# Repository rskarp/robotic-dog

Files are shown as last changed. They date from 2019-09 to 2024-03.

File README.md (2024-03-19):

# Robotic Dog
This project was conducted as my Honors project in Computer Science at Colby College from January-May 2019. The project included simulating robotic limb movement using Python, programming and Arduino Uno to control 12 servo motors (3 per limb) using C++, designing robotic dog limbs using CAD software, laser cutting the limbs and assembling the dog with servo motors, writing a paper on this work, and giving an oral presentation.
RoboticDog

## Project Description
As robots develop the capability to perform more complicated tasks, stable locomotion will become a basic required element of all mobile robots. While walking robots may have various numbers of legs, four legs provide a reasonably stable platform without requiring excessive amounts of power and resources that would be necessary to control robots with more limbs. It is useful to base the gait patterns of these robotic quadrupeds on existing quadrupeds in nature, such as dogs. This project explores three different joint control algorithms in simulation using Python3.7 and on a robotic dog controlled by an Arduino Uno. The three algorithms include an inverse kinematics solution based on a predetermined foot trajectory, a forward kinematic solution based on joint angles collected from biological data, and a waypoint solution, which was found to be optimal for this project. The robot described in this paper was created specifically as a tool to explore different motor control strategies for reproducing canine gait patterns in robotic limbs; however, these motor control concepts are applicable to more complicated limbed robots as well.

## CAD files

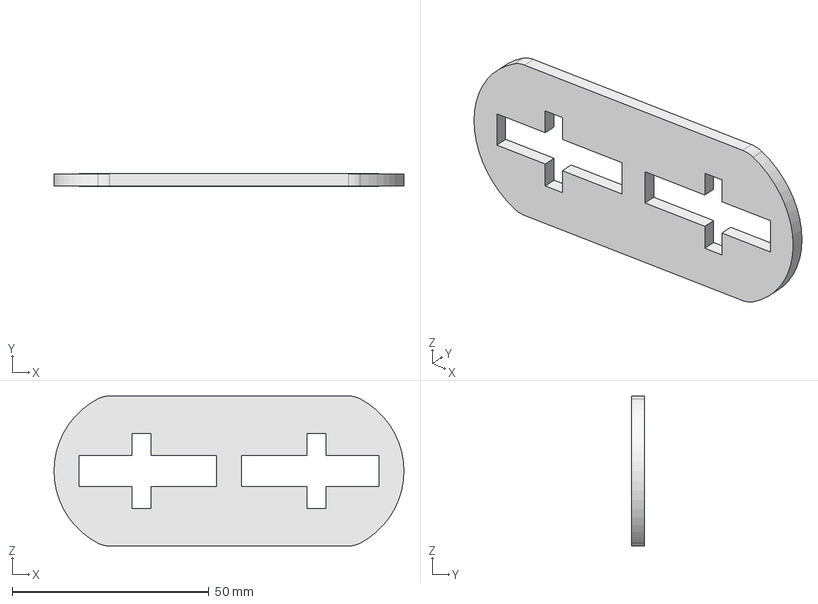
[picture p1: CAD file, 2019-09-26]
CAD/thigh2.FCStd
88.9 x 3.18 x 38.1 mm

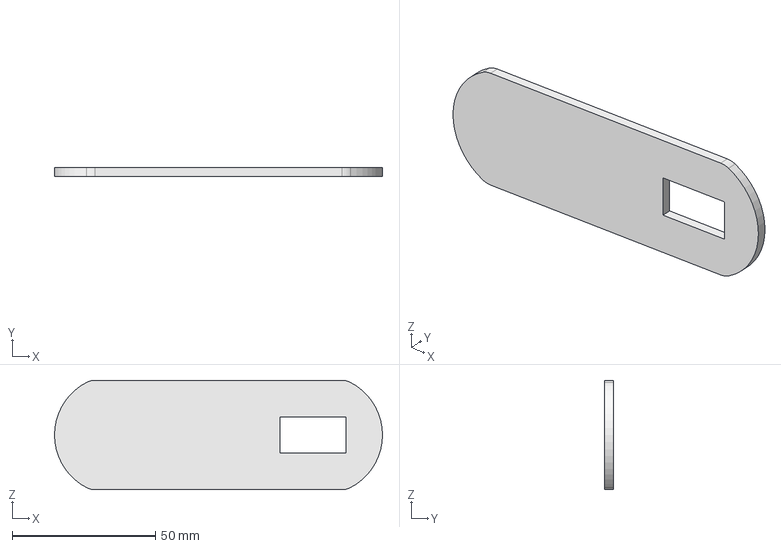
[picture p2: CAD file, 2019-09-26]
CAD/shin3.FCStd
114.3 x 3.17 x 38.1 mm

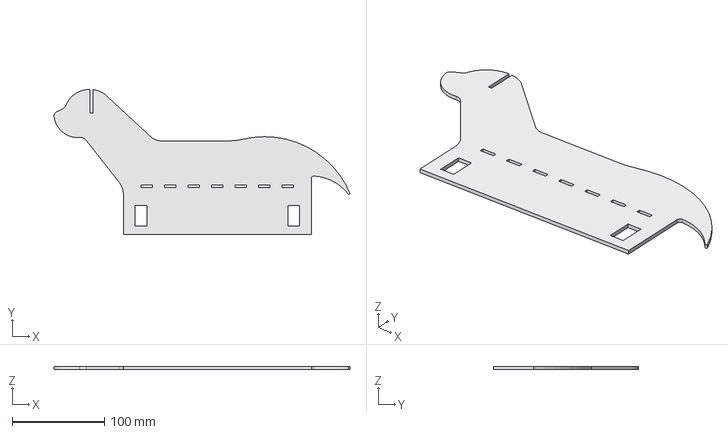
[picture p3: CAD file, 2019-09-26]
CAD/bodySideSlit.FCStd
320.2 x 157.2 x 3.17 mm

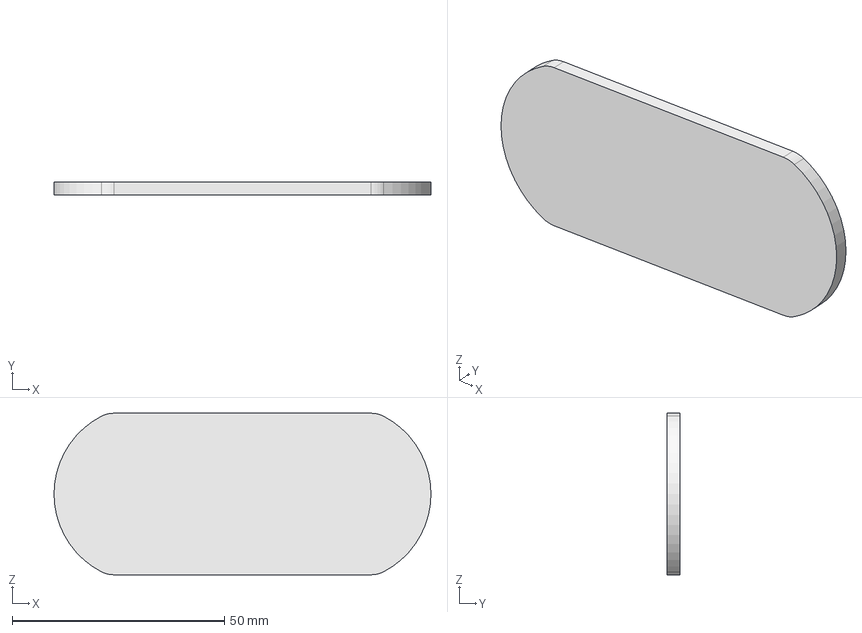
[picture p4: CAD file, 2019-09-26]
CAD/thigh3.FCStd
88.9 x 3.18 x 38.1 mm

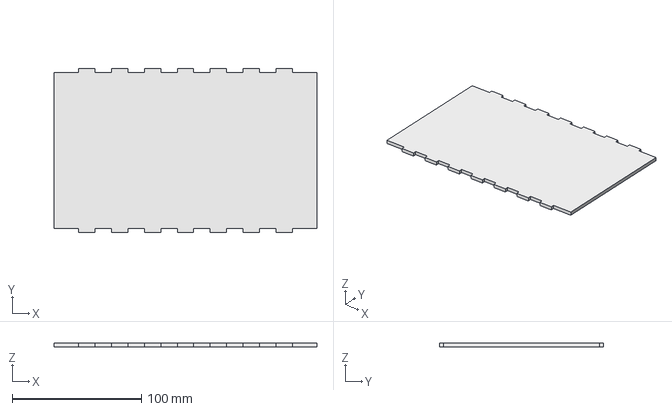
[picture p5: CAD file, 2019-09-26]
CAD/bodyBase.FCStd
203.2 x 127.0 x 3.17 mm

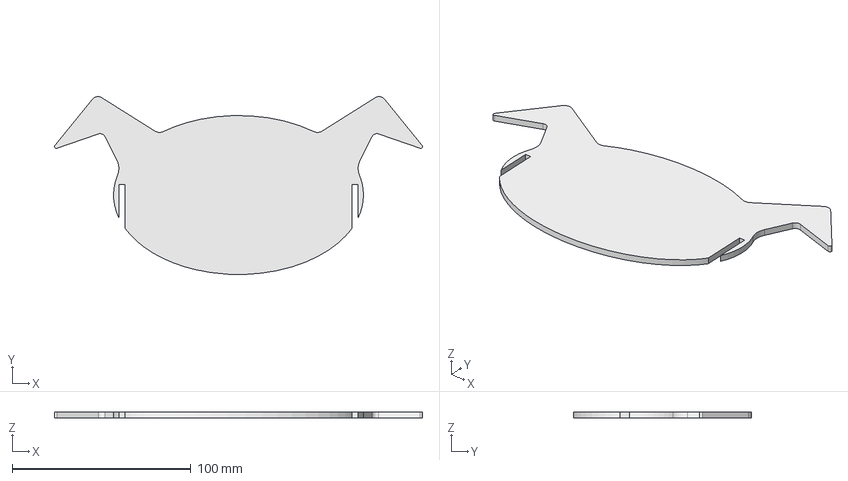
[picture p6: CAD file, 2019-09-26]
CAD/head.FCStd
205.7 x 99.4 x 3.17 mm

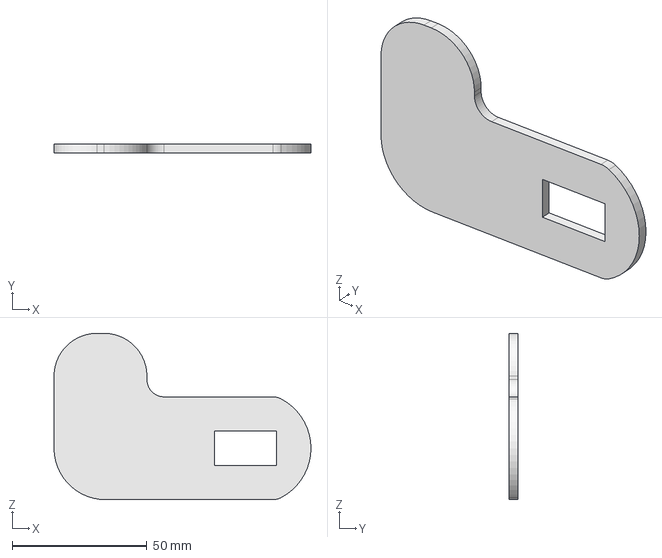
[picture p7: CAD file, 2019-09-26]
CAD/foot2.FCStd
95.2 x 3.17 x 61.6 mm

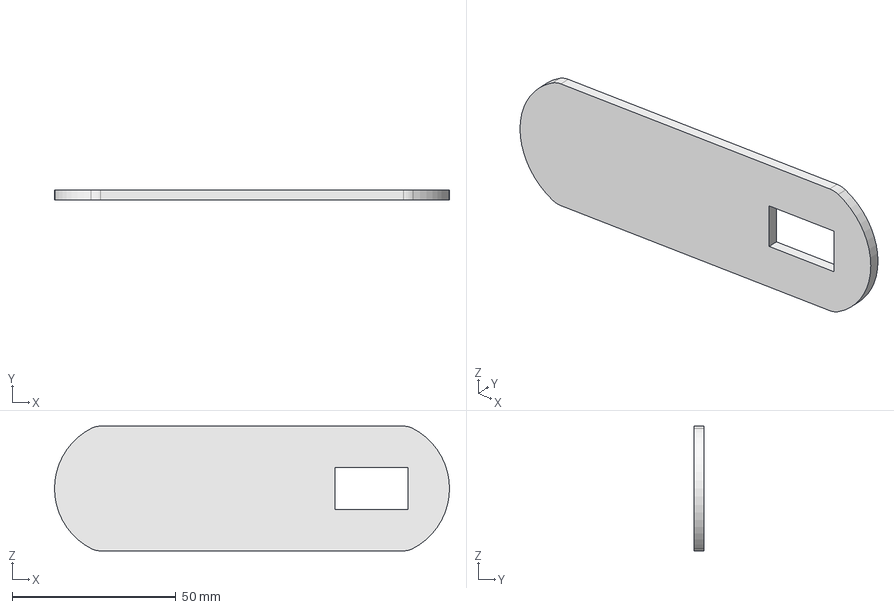
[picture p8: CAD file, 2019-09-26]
CAD/foot.FCStd
120.7 x 3.18 x 38.1 mm

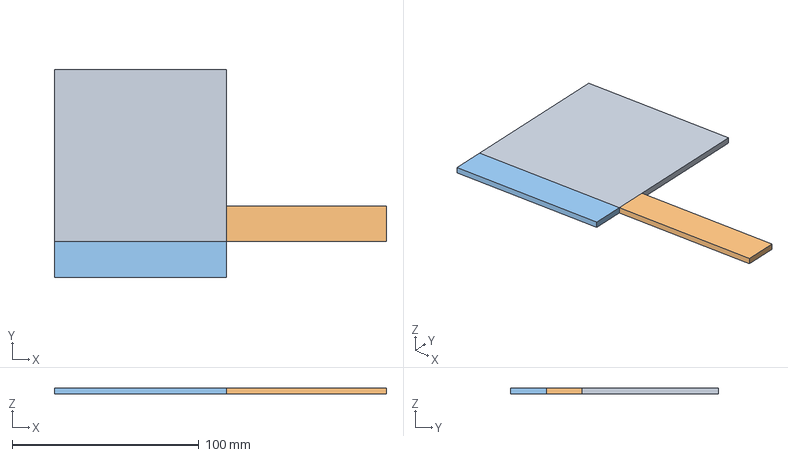
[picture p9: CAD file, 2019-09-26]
CAD/basePlate.FCStd
177.8 x 111.1 x 3.17 mm
Base
Back
Side

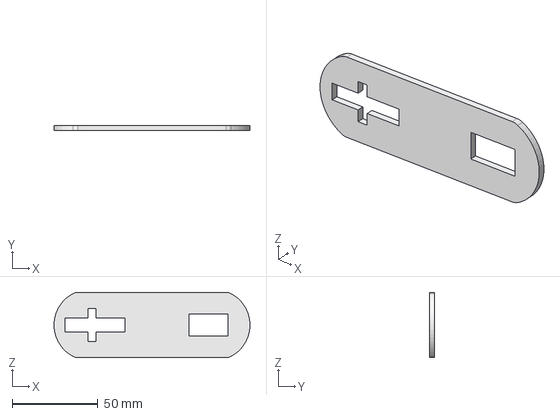
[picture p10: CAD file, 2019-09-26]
CAD/shin2.FCStd
114.3 x 3.17 x 38.1 mm

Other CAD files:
CAD/shin1.FCStd
CAD/thigh1.FCStd

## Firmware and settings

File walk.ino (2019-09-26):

/*
 * Riley Karp
 * CS483 Honors Research - Robotic Dog
 * Leg Control - Step to target location
 * 10 March 2019
 */

 #include <avr/io.h>
 #include "Adafruit_PWMServoDriver.h" // PWM Motor Driver
 #include "USART.h" //library w/ serial bus functions
 #include <stdio.h> // library w/ sprintf() string formatting

 /* Define constants */
 #define servoMin  170 // min pulse length out of 4096 (0 degrees)
 #define servoMed  370 // med pulse length out of 4096 (90 degrees)
 #define servoMax  510 // max pulse length out of 4096 (130 degrees)
 #define hipHL 0 // motor number for FRONT LEFT HIP
 #define kneeHL 1 // motor number for FRONT LEFT KNEE
 #define ankleHL 2 // motor number for FRONT LEFT ANKLE
 #define hipHR 4 // motor number for HIND LEFT HIP
 #define kneeHR 5 // motor number for HIND LEFT KNEE
 #define ankleHR 6 // motor number for HIND LEFT ANKLE
 #define hipFL 8 // motor number for FRONT RIGHT HIP
 #define kneeFL 9 // motor number for FRONT RIGHT KNEE
 #define ankleFL 10 // motor number for FRONT RIGHT ANKLE
 #define hipFR 12 // motor number for HIND RIGHT HIP
 #define kneeFR 13 // motor number for HIND RIGHT KNEE
 #define ankleFR 14 // motor number for HIND RIGHT ANKLE
 #define pi 3.141592653589793238462643383279502884197169399375105820974944592307816406286208998

 /* Initialize global variables */
 const int numAngles = 8; // initialize number of waypoint angles
 Adafruit_PWMServoDriver driver = Adafruit_PWMServoDriver(); // motor driver object

// float hipAngles[numAngles] = {-107.53,-115.32, -120.90,-120.89,-122.7,-133.56,-132.03,-126.2,-117.23,-105,-79.74,-88.8,-104.19};
// float kneeAngles[numAngles] = {16.76,15.07,11.30,5.73,0.94,7.32,12.75,16.97,20,21.15,13.79,13.34,14.76};
// float ankleAngles[numAngles] = {31.44,35.70,34.52,23.72,15.29,44.96,53.55,55.09,51,41.14,12,16.81,31};
 
 float hipAngles[numAngles] = {-7.53,25,0,-33,-25,-10,10,15};
 float kneeAngles[numAngles] = {-36.76,-43,-45,-48,-30,-40,-35,-30};
 float ankleAngles[numAngles] = {31.44,48,60,66,45,40,30,38};
 int pulse;

 bool FL = false;
 bool FR = true;
 bool HL = false;
 bool HR = false;
 int FLi = 6;
 int FRi = 1;
 int HLi = 5;
 int HRi = 7;

 // FRONT LEFT FOOT
 float thetaH_FL = (hipAngles[0])*pi/180;
 float thetaK_FL = (kneeAngles[0])*pi/180;
 float thetaA_FL = (ankleAngles[0])*pi/180;
 float targetH_FL = (hipAngles[FLi])*pi/180;
 float targetK_FL = (kneeAngles[FLi])*pi/180;
 float targetA_FL = (ankleAngles[FLi]-5)*pi/180;

 // FRONT RIGHT FOOT
 float thetaH_FR = (hipAngles[0])*pi/180;
 float thetaK_FR = (kneeAngles[0])*pi/180;
 float thetaA_FR = (ankleAngles[0])*pi/180;
 float targetH_FR = (hipAngles[FRi])*pi/180;
 float targetK_FR = (kneeAngles[FRi])*pi/180;
 float targetA_FR = (ankleAngles[FRi])*pi/180;

 // HIND LEFT FOOT
 float thetaH_HL = (hipAngles[0])*pi/180;
 float thetaK_HL = (kneeAngles[0])*pi/180;
 float thetaA_HL = (ankleAngles[0])*pi/180;
 float targetH_HL = (hipAngles[HLi])*pi/180;
 float targetK_HL = (kneeAngles[HLi])*pi/180;
 float targetA_HL = (ankleAngles[HLi]+8)*pi/180;

 // HIND RIGHT FOOT
 float thetaH_HR = (hipAngles[0])*pi/180;
 float thetaK_HR = (kneeAngles[0])*pi/180;
 float thetaA_HR = (ankleAngles[0])*pi/180;
 float targetH_HR = (hipAngles[HRi])*pi/180;
 float targetK_HR = (kneeAngles[HRi])*pi/180;
 float targetA_HR = (ankleAngles[HRi])*pi/180;

 
 /* Returns the pulse length corresponding to the given angle between 0 and 130 degrees (input angle is in radians) */
 int radToPulse( int joint, float rad ) {
  // y = mx + b for DH angle to pulse
  pulse = int(float(servoMed-servoMin)*rad/(pi/2) + servoMed);
  // make sure pulse is within range
  if( pulse > servoMax ) {
    pulse = servoMax;
  }
  else if(pulse < servoMin) {
    pulse = servoMin;
  }
  return pulse;
 }

 /* Moves the given joint to the given angle */
 void moveJoint( int joint, float angle ) {
  driver.setPWM( joint, 0, radToPulse(joint,angle) );
 }
 
 int main() {
  initUSART();
  init(); // haven't yet figured out why this is necessary, but it is
  driver.begin(); // start motor driver object
  driver.setPWMFreq(60); // analog servos run at ~60 hz
  
  DDRC = 0b00110000; // configure OC1B pin PC[5:4] as output
  SREG |= 0b10000000; // enable global interrupts

  // move legs to starting position
  moveJoint( hipFR, thetaH_FR );
  moveJoint( kneeFR, thetaK_FR );
  moveJoint( ankleFR, thetaA_FR );

  moveJoint( hipHL, -thetaH_HL );
  moveJoint( kneeHL, -thetaK_HL);
  moveJoint( ankleHL, -thetaA_HL );
  
  moveJoint( hipFL, -thetaH_FL );
  moveJoint( kneeFL, -thetaK_FL );
  moveJoint( ankleFL, -thetaA_FL );
  
  moveJoint( hipHR, thetaH_HR );
  moveJoint( kneeHR, thetaK_HR );
  moveJoint( ankleHR, thetaA_HR );
      
  printString("start\n");
  _delay_ms(1000);
    
  while( true) {
    // FRONT RIGHT LEG
    thetaH_FR += (targetH_FR-thetaH_FR)/20.0;
    thetaK_FR += (targetK_FR-thetaK_FR)/20.0;
    thetaA_FR += (targetA_FR-thetaA_FR)/20.0;
    moveJoint( hipFR, thetaH_FR );
    moveJoint( kneeFR, thetaK_FR );
    moveJoint( ankleFR, thetaA_FR );

    // HIND LEFT LEG
    thetaH_HL += (targetH_HL-thetaH_HL)/20.0;
    thetaK_HL += (targetK_HL-thetaK_HL)/20.0;
    thetaA_HL += (targetA_HL-thetaA_HL)/20.0;
    moveJoint( hipHL, -thetaH_HL );
    moveJoint( kneeHL, -thetaK_HL);
    moveJoint( ankleHL, -thetaA_HL );

    // FRONT LEFT LEG
    thetaH_FL += (targetH_FL-thetaH_FL)/20.0;
    thetaK_FL += (targetK_FL-thetaK_FL)/20.0;
    thetaA_FL += (targetA_FL-thetaA_FL)/20.0;
    moveJoint( hipFL, -thetaH_FL );
    moveJoint( kneeFL, -thetaK_FL );
    moveJoint( ankleFL, -thetaA_FL );

    // HIND RIGHT LEG
    thetaH_HR += (targetH_HR-thetaH_HR)/20.0;
    thetaK_HR += (targetK_HR-thetaK_HR)/20.0;
    thetaA_HR += (targetA_HR-thetaA_HR)/20.0;
    moveJoint( hipHR, thetaH_HR );
    moveJoint( kneeHR, thetaK_HR );
    moveJoint( ankleHR, thetaA_HR );

    if( (abs(thetaH_FR-targetH_FR) < 0.08) and
        (abs(thetaH_HL-targetH_HL) < 0.08) and
        (abs(thetaH_FL-targetH_FL) < 0.08) and
        (abs(thetaH_HR-targetH_HR) < 0.08) ) {

      // FRONT RIGHT UP
      if( FR ) {
        FRi += 1;
        if(FRi >= 4) {
          FR = false;
          HL = true;
          HLi = 0;
          FLi += 1;
          HRi -= 1;
        }
      }
      // HIND LEFT UP
      else if( HL ) {
        HLi += 1;
        if(HLi >= 4) {
          HL = false;
          HLi = 7;
          FL = true;
          FLi = 0;
          FRi += 1;
          HRi -= 1;
        }
      }
      // FRONT LEFT UP
      else if( FL ) {
        FLi += 1;
        if(FLi >= 4) {
          FL = false;
          HR = true;
          HRi = 0;
          FRi += 1;
          HLi -= 1;
        }
      }
      // HIND RIGHT UP
      else if(HR) {
        HRi += 1;
        if(HRi >= 4) {
          HR = false;
          HRi = 7;
          FR = true;
          FRi = 0;
          FLi += 1;
          HLi -= 1;
        }
      }

      // FRONT LEFT FOOT
      targetH_FL = (hipAngles[FLi])*pi/180;
      targetK_FL = (kneeAngles[FLi])*pi/180;
      targetA_FL = (ankleAngles[FLi]-5)*pi/180;
    
      // FRONT RIGHT FOOT
      targetH_FR = (hipAngles[FRi])*pi/180;
      targetK_FR = (kneeAngles[FRi])*pi/180;
      targetA_FR = (ankleAngles[FRi])*pi/180;
    
      // HIND LEFT FOOT
      targetH_HL = (hipAngles[HLi])*pi/180;
      targetK_HL = (kneeAngles[HLi])*pi/180;
      targetA_HL = (ankleAngles[HLi]+8)*pi/180;
    
      // HIND RIGHT FOOT
      targetH_HR = (hipAngles[HRi])*pi/180;
      targetK_HR = (kneeAngles[HRi])*pi/180;
      targetA_HR = (ankleAngles[HRi])*pi/180;
    }
    
  }
  return 0;
 }
